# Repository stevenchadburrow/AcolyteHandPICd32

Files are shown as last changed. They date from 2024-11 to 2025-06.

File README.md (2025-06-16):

<b><h1>Acolyte Hand PIC'd 32 Retraux Computer and Video Game Console</h1></b>

<b>Background</b>

Why build a "computer"?  Why build a "video game console"?  

I had been programming video games for about 20 years before all of this.  It started in high school on Borland Turbo C++ in the computer lab, and then in college on a Ubuntu Linux computer with g++ and OpenGL.  Most of my early attempts are not even worth mentioning though I tried different genres such as FPS and RTS.  After graduate school and getting a job at the local college as a math teacher, I began trying to make a non-violent video game, namely a <a href="https://en.wikipedia.org/wiki/Harvest_Moon_(video_game)">Harvest Moon</a> clone.  It seems that <a href="https://en.wikipedia.org/wiki/Stardew_Valley">Stardew Valley</a> beat me to it!  After many attempts on many different platforms, including Linux/OpenGL/C++, HTML/Javascript, and Android/Java, I have declared them all as 'demos', though I learned a lot from that time.  Meanwhile, I began programming 'arcade' video games for our annual Math Appreciation Day events, to have on display and allow students to play during the event.  A few are listed <a href="https://github.com/stevenchadburrow/MathDayGames">here</a>.  

In Fall 2021, after starting research on a water-based calculator, I thought to myself, "Wouldn't electricity be so much easier?"  After stumbling upon <a href="https://wilsonminesco.com/">Garth Wilson's 6502 Primer</a>, I emailed him and he invited me to join the <a href="http://forum.6502.org/">6502.org Forum</a>.  I began researching and prototyping (aka breadboarding) with basic logic chips, and learning how to create schematics.  While learning more about digital electronics, I found The 8-Bit Guy, Adrian's Digital Basement, and Ben Eater on Youtube.

Inspired by The 8-Bit Guy's <a href="https://www.youtube.com/watch?v=ayh0qebfD2g">"Dream Computer"</a>, and after many initial attempts (aka failures) and a couple of awesome successes, I eventually produced the original <a href="https://github.com/stevenchadburrow/AcolyteComputer">Acolyte Computer</a> using a W65C02 processor.  I had great help from Garth Wilson and the guys on the 6502.org Forum as I worked through many prototypes to get to that point.  I was able to display this and other projects at the Math Appreciation Day events playing video games such as Space Invaders, Tetris, and Rogue.

From there, the project grew to the <a href="https://github.com/stevenchadburrow/NewAcolyte">New Acolyte</a> coupled with an XC9572XL CPLD, then the <a href="https://github.com/stevenchadburrow/Acolyte816">Acolyte '816</a> using a W65C816 processor coupled with a PIC16F886 microcontroller as a bootloader.  Wanting to continue pursuing PIC microcontrollers, I created the original <a href="https://github.com/stevenchadburrow/AcolyteHandPICd">Acolyte Hand PIC'd</a> using the PIC18F47J13 microcontroller, then the <a href="https://github.com/stevenchadburrow/AcolyteHandPICd24">Acolyte Hand PIC'd 24</a> using the PIC24EP512GP204 microcontroller finally without a coupled CPLD.  During Summer 2024, I programmed a 2-player <a href="https://www.youtube.com/watch?v=8EHRpKk9gPc">Pokemon demo</a> using <a href="https://tuxemon.org/">Tuxemon</a> art assets, pushing that PIC24 to the limit.

This project, the Acolyte Hand PIC'd 32, is supposed to show the culmination of my knowledge in PCB design and microcontroller programming over the past 3 years.  The intention is to create a standardized development platform for many new video games that will be displayed during the Math Appreciation Day events.

<b>Microcontroller</b>

PIC32MZ2048EFH144 running at 200 MHz
<br>
Internal memory of 512KB of RAM and 2MB of Flash ROM

<b>Video</b>

VGA 800x600 max resolution (720x512 typical resolution) at 72 Hz with 256 colors or 65K colors

<b>Audio</b>

Dual 8-bit audio channels

<b>HID</b>

2x Sega Genesis controller ports
<br>
Dual PS/2 port for keyboard and mouse through splitter
<br>
USB port for keyboard, mouse, or Xbox-360 controller

<b>File System</b>

Elm-Chan's <a href="http://elm-chan.org/fsw/ff/">FatFS Generic FAT Filesystem Module</a> using SPI Micro SD Card adapter
<br>
(use command 'sudo mkfs.vfat /dev/sdX' to format SDcard)

<b>UART</b>

FT232RL USB-to-UART adapter
<br>
(use command 'sudo picocom /dev/ttyUSB0' for default 9600 baud connection)

<b>Custom Applications</b>

Tetra - Tetris clone recopied from my previous PIC-related projects
<br>
Scratchpad - Proof-of-concept 'text editor' without save/load features
<br>
AV Demo - Audio/Video playback of modified video files with a resolution 240x192 at 15 FPS with 65K colors and dual 8-bit audio

<b>Gameboy Emulator</b>

Mahyar Koshkouei's <a href="https://github.com/deltabeard/Peanut-GB">Peanut-GB (with MiniGB-APU) Gameboy Emulator</a>
<br>
Added support for GBC default color palettes, custom palettes, game file save/load, and screen size and refresh rate adjustments
<br>
Tested with many games, including: Tetris, Dr. Mario, Balloon Kid, Zelda: Link's Awakening, Tobu Tobu Girl, Pokemon Red, and Pokemon Kanto Expansion Pak

<b>Links</b>

<a href="https://www.aidanmocke.com/">https://www.aidanmocke.com/</a> for a bunch of PIC32MZ projects (without Harmony), including USB.<br>
<a href="http://elm-chan.org/">http://elm-chan.org/</a> for a bunch of projects, including MMC (aka SDcard) and FatFs.<br>
<a href="https://github.com/deltabeard/">https://github.com/deltabeard/</a> for a bunch of projects, including Peanut-GB and MiniGB-APU projects.<br>
<a href="https://hackaday.com/2025/01/13/homebrew-retro-console-runs-on-pic32/">https://hackaday.com/2025/01/13/homebrew-retro-console-runs-on-pic32/</a> for the Hack-A-Day article!<br>

<b>Look Ma, no bodges! (showing Version 2 board)</b>
<br>
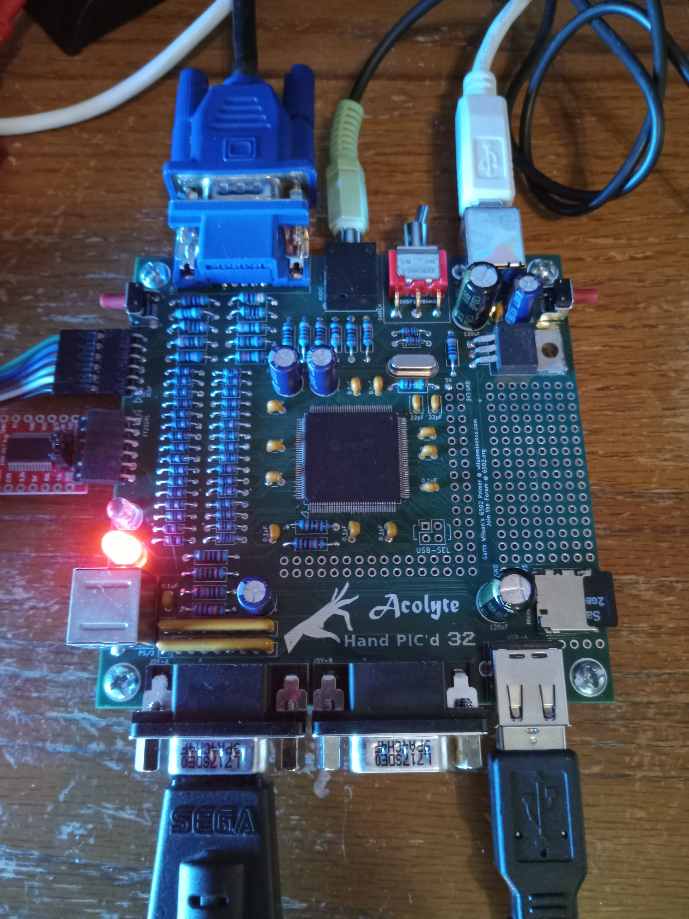
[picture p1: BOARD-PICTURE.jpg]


<b>3D printed case fits perfectly! (showing Version 1 board)</b>
<br>
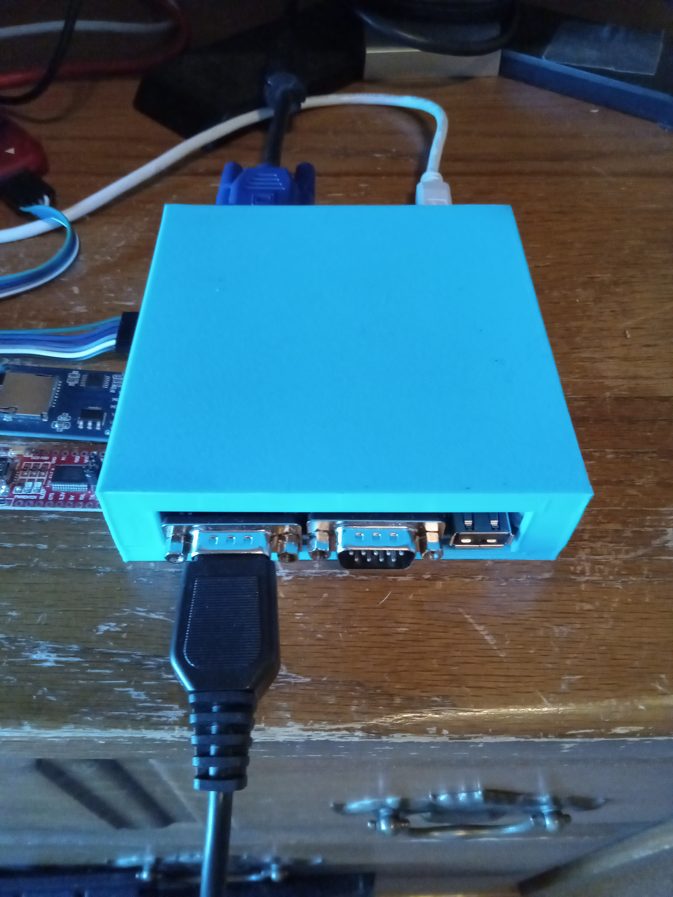
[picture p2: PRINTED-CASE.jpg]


<b>Main menu format with splash screen.</b>
<br>


<b>Gotta love some 2-player Tetris!</b>
<br>
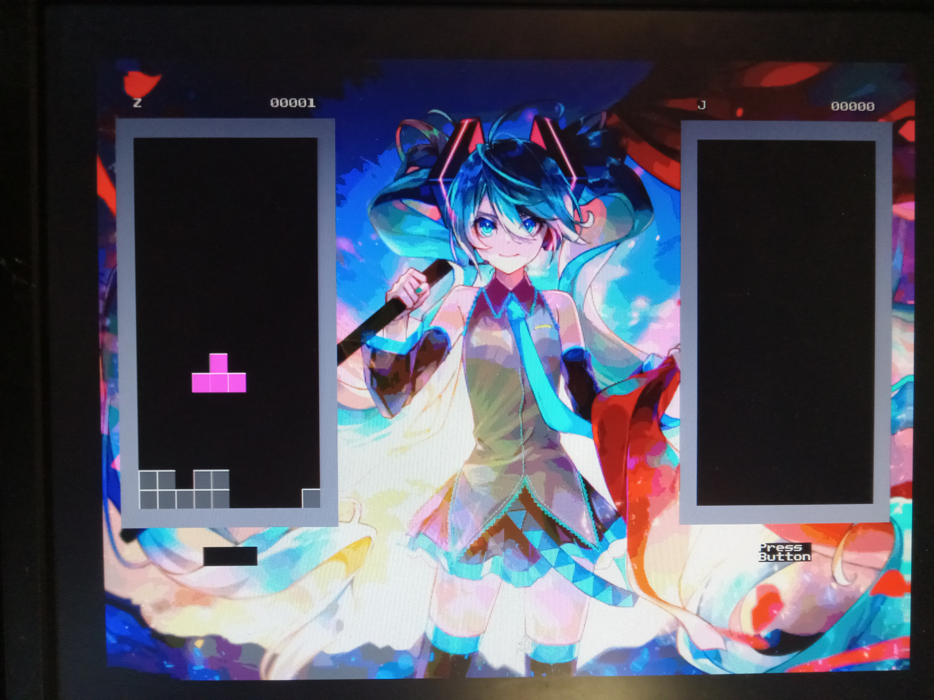
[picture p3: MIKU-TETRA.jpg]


<b>It can now play any Gameboy game!</b>
<br>
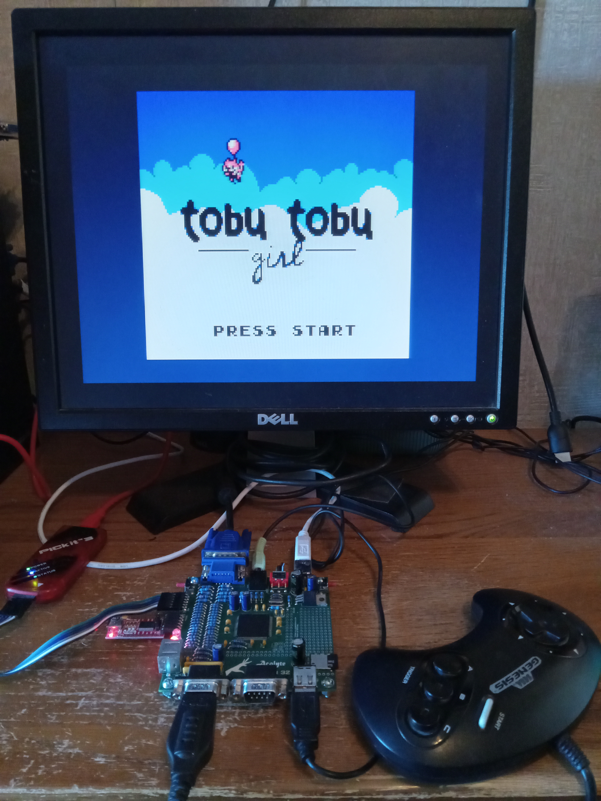
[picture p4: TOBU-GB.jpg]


<b>Audio/Video playback running at 65K colors and dual 8-bit audio.</b>
<br>
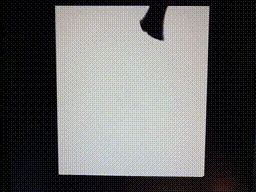
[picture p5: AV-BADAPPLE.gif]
&nbsp;&nbsp;&nbsp;&nbsp;&nbsp;&nbsp;&nbsp;&nbsp;

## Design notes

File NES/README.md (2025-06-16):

<b>NES Emulator for PIC32MZ</b>

*** These files are for the AcolyteHandPICd32 project, but do not show off it's full capability. ***

*** NesEmulator.c is my Linux/OpenGL port, but without audio.  It was made for debugging purposes. ***

These files contain an NES emulator for the PIC32MZ.  It currently is running at 260 MHz (overclocked from 252 MHz max).  Most games run at perfect speed at 20 FPS with audio enabled, even Super Mario Bros 3!

This emulator currently works with the following mappers: NROM, UNROM, CNROM, ANROM, MMC1, and MMC3 (mostly implemented).

Some MMC3 games have issues with IRQ timing, though adjusting both cycle and scanline delays help in most cases.  Mega Man 3, Mega Man 4, and Ninja Gaiden 2 all need these adjusted to even run!  Crystalis needs it adjusted to remove the seam.

Only one hack is currently employed: Sprite priority for Super Mario Bros 3 (though also helps a little in Prince of Persia).

The journey has been documented on the 6502.org Forum, here: http://forum.6502.org/viewtopic.php?f=1&t=8236

Link to a demo video featuring Super Mario Bros 3 here: https://youtu.be/WGrEMQLWrP4

Here is a list of games that are supported, with notes:

1942<br>
1943: Battle for Midway<br>
ADnD: Heroes of the Lance<br>
Adventure Island<br>
Adventure Island 2<br>
Adventure Island 3<br>
Adventures of Lolo<br>
Adventures of Lolo 2<br>
Adventures of Lolo 3<br>
Alwa's Awakening<br>
Arkanoid<br>
Arkista's Ring<br>
Athena<br>
Balloon Fight<br>
Baseball<br>
Battle Kid<br>
Battletoads<Br>
Batman<br>
Battle of Olympus<br>
Bionic Commando<br>
Blade Buster<br>
Blades of Steel<br>
Blaster Master<br>
Boulder Dash<br>
Battletoads and Double Dragon<br>
Bubble Bobble<br>
Castlevania<br>
Castlevania 2<br>
Chip and Dale<br>
Clash at Demonhead<br>
Clu Clu Land<br>
Cobra Triangle<br>
Contra<br>
Championship Rally<br>
Crystalis - Needs IRQ adjustments to remove seam<br>
Double Dragon<br>
Double Dragon 2<br>
Dig Dug<br>
Donkey Kong<br>
Donkey Kong Jr<br>
Double Dribble<br>
Dragon Warrior<br>
Dragon Warrior 2<br>
Dragon Warrior 3<br>
Dragon Warrior 4<br>
Dr. Mario<br>
Duck Tales<br>
Excitebike - Scroll scanline is too high<br>
Faria<br>
Faxanadu<br>
Final Fantasy<br>
Formula One: Built to Win<br>
Galaga<br>
Gauntlet 2 - Needs IRQ adjustments to help seam and status bar, though never perfect<br>
Ghost Lion<br>
Ghosts and Goblins<br>
Golden Guardian Gun Girl<br>
Golf<br>
Gradius<br>
Guardian Legend - Bottom status bar comes in and out sometimes<br>
Ice Climber<br>
Joust<br>
Jurassic Park<br>
Kid Icarus<br>
King's Quest 5<br>
Kira Kira Star Night<br>
Kirby's Adventure<br>
Kung Fu<br>
Layla<br>
Legacy of Wizards<br>
Lemmings<br>
Life Force<br>
Little Mermaid<br>
Little Nemo<br>
Little Samson<br>
LJ-65<br>
Lode Runner<br>
Mach Rider<br>
Marble Madness<br>
Mario Bros<br>
Mega Man<br>
Mega Man 2<br>
Mega Man 3 - Must have IRQ turned off at boot to run<br>
Mega Man 4 - Must have IRQ turned off at boot to run<br>
Mega Man 5<br>
Mega Man 6<br>
Metal Gear<br>
Metroid<br>
Micro Mages<br>
Micro Mages: Second Quest<br>
Miedow<br>
Moon Crystal<br>
Metal Storm<br>
Ninja Gaiden<br>
Ninja Gaiden 2 - Needs IRQ adjusted so game is not halted<br>
Ninja Gaiden 3<br>
Pac-man<br>
Paperboy<br>
Paperboy 2<br>
Prince of Persia - Sprite priority hack only helps a little when behind columns<br>
Project Blue<br>
Rad Racer<br>
Rampage<br>
RC Pro AM<br>
RC Pro AM 2<br>
River City Ransom<br>
S.C.A.T.<br>
Skate or Die<br>
Slalom<br>
Sokoban<br>
Super Mario Bros<br>
Super Mario Bros 2<br>
Super Mario Bros 3 - Sprite priority hack helps a lot, can unadjust IRQ to make multi-scrolling perfect<br>
Super Mario Bros: Lost Levels<br>
Smash TV<br>
Super Off Road<br>
Solstice<br>
Spy Hunter<br>
Silver Surfer<br>
Star Tropics - Top tiles of bottom status bar are cut off<br>
Strider<br>
Super C<br>
Tecmo Super Bowl<br>
Tetris<br>
Time Lord<br>
TMNT<br>
TMNT 2<br>
TMNT 3<br>
Turrican<br>
Ultima: Quest of the Avatar<br>
Wario's Woods<br>
Witch N' Wiz<br>
Wizardry - Proving Grounds<br>
Wizards and Warriors<br>
Pro Wrestling - Needs v-sync flag hack after title screen<br>
Legend of Zelda<br>
Zelda 2: Link's Adventure<br>
Zen: Intergalagic Ninja<br>

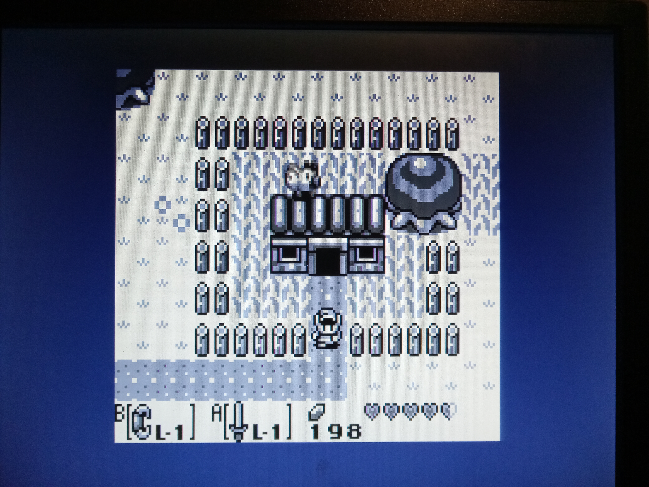
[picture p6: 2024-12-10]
ZELDA-GB.jpg

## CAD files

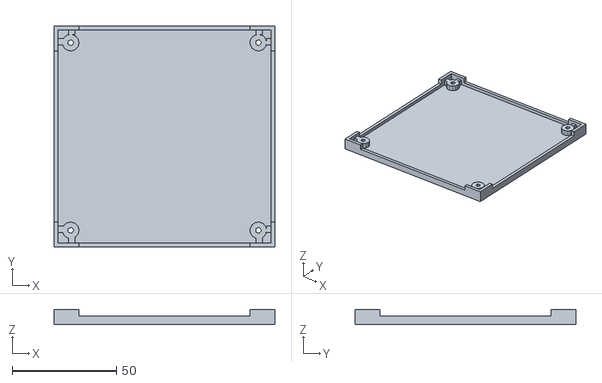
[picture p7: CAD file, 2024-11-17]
HandPICd32-BoxBottom.stl
106.0 x 106.0 x 7.00

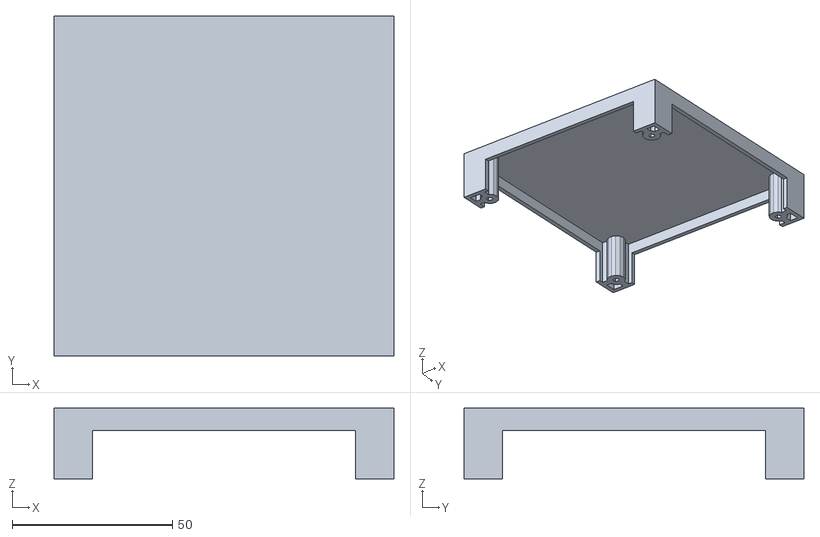
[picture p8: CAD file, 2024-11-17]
HandPICd32-BoxTop.stl
106.0 x 106.0 x 22.0

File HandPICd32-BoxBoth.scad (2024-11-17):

// Both together, just for visuals

//color("#808080") {
shift = 0;



// beginning of top half
rotate([180,0,0]) {
translate([0,-100,-20]) {
    
// top
translate([-3, -3, -2]) {
    difference() {
        cube([106, 106, 2], center = false);
        
    }
}

// back
translate([-3, -3, 0]) {
    difference() {
        cube([106, 2, 20], center = false);
        translate([3+9, -1, 5]) {
            cube([82, 4, 16], center = false);
        }
    }
}

// front
translate([-3, 101, 0]) {
    difference() {
        cube([106, 2, 20], center = false);
        translate([3+9, -1, 5]) {
            cube([82, 4, 16], center = false);
        }
    }
}

// right
translate([-3, -3, 0]) {
    difference() {
        cube([2, 106, 20], center = false);
        translate([-1, 3+9, 5]) {
            cube([4, 82, 16], center = false);
        }
    }
}

// left
translate([101, -3, 0]) {
    difference() {
        cube([2, 106, 20], center = false);
        translate([-1, 3+9, 5]) {
            cube([4, 82, 16], center = false);
        }
    }
}

// corner
translate([5, 5, 0]) {
    difference() {
        cylinder(20, 4, 4);
        translate([0, 0, -1]) {
            cylinder(21.25, 1.5, 1.5);
        }
    }
}
translate([4, -2, 0]) {
    cube([3, 4, 20], center = false);
}
translate([-2, 4, 0]) {
    cube([4, 3, 20], center = false);
}

// corner
translate([95, 5, 0]) {
    difference() {
        cylinder(20, 4, 4);
        translate([0, 0, -1]) {
            cylinder(21.25, 1.5, 1.5);
        }
    }
}
translate([94, -2, 0]) {
    cube([3, 4, 20], center = false);
}
translate([98, 4, 0]) {
    cube([4, 3, 20], center = false);
}

// corner
translate([95, 95, 0]) {
    difference() {
        cylinder(20, 4, 4);
        translate([0, 0, -1]) {
            cylinder(21.25, 1.5, 1.5);
        }
    }
}
translate([94, 98, 0]) {
    cube([3, 4, 20], center = false);
}
translate([98, 94, 0]) {
    cube([4, 3, 20], center = false);
}

// corner
translate([5, 95, 0]) {
    difference() {
        cylinder(20, 4, 4);
        translate([0, 0, -1]) {
            cylinder(21.25, 1.5, 1.5);
        }
    }
}
translate([4, 98, 0]) {
    cube([3, 4, 20], center = false);
}
translate([-2, 94, 0]) {
    cube([4, 3, 20], center = false);
}

}}
// end of top half



// beginning of bottom half
translate([0,0,-5]) {

// bottom
translate([-3, -3, -2]) {
    difference() {
        cube([106, 106, 2], center = false);
        translate([3+5, 3+5, -1]) {
            cylinder(4, 3, 3);
        }
        translate([3+95, 3+5, -1]) {
            cylinder(4, 3, 3);
        }
        translate([3+95, 3+95, -1]) {
            cylinder(4, 3, 3);
        }
        translate([3+5, 3+95, -1]) {
            cylinder(4, 3, 3);
        }
    }
}

// front
translate([-3, -3, 0]) {
    difference() {
        cube([106, 2, 5], center = false);
        translate([12, -5, 2]) {
            cube([82, 10, 4], center = false);
        }
    }
}

// back
translate([-3, 101, 0]) {
    difference() {
        cube([106, 2, 5], center = false);
        translate([12, -5, 2]) {
            cube([82, 10, 4], center = false);
        }
    }
}

// left
translate([-3, -3, 0]) {
    difference() {
        cube([2, 106, 5], center = false);
        translate([-5, 12, 2]) {
            cube([10, 82, 4], center = false);
        }
    }
}

// right
translate([101, -3, 0]) {
    difference() {
        cube([2, 106, 5], center = false);
        translate([-5, 12, 2]) {
            cube([10, 82, 4], center = false);
        }
    }
}

// front left corner
translate([5, 5, 0]) {
    difference() {
        cylinder(3.25, 4, 4);
        translate([0, 0, -1]) {
            cylinder(4.5, 1.5, 1.5);
        }
    }
}
translate([4, -1, 0]) {
    cube([3, 4, 3.25], center = false);
}
translate([-1, 4, 0]) {
    cube([4, 3, 3.25], center = false);
}

// front right corner
translate([95, 5, 0]) {
    difference() {
        cylinder(3.25, 4, 4);
        translate([0, 0, -1]) {
            cylinder(4.5, 1.5, 1.5);
        }
    }
}
translate([94, -1, 0]) {
    cube([3, 4, 3.25], center = false);
}
translate([99, 4, 0]) {
    cube([4, 3, 3.25], center = false);
}

// back right corner
translate([95, 95, 0]) {
    difference() {
        cylinder(3.25, 4, 4);
        translate([0, 0, -1]) {
            cylinder(4.5, 1.5, 1.5);
        }
    }
}
translate([94, 99, 0]) {
    cube([3, 4, 3.25], center = false);
}
translate([99, 94, 0]) {
    cube([4, 3, 3.25], center = false);
}

// back left corner
translate([5, 95, 0]) {
    difference() {
        cylinder(3.25, 4, 4);
        translate([0, 0, -1]) {
            cylinder(4.5, 1.5, 1.5);
        }
    }
}
translate([4, 99, 0]) {
    cube([3, 4, 3.25], center = false);
}
translate([-1, 94, 0]) {
    cube([4, 3, 3.25], center = false);
}
}
// end of bottom half

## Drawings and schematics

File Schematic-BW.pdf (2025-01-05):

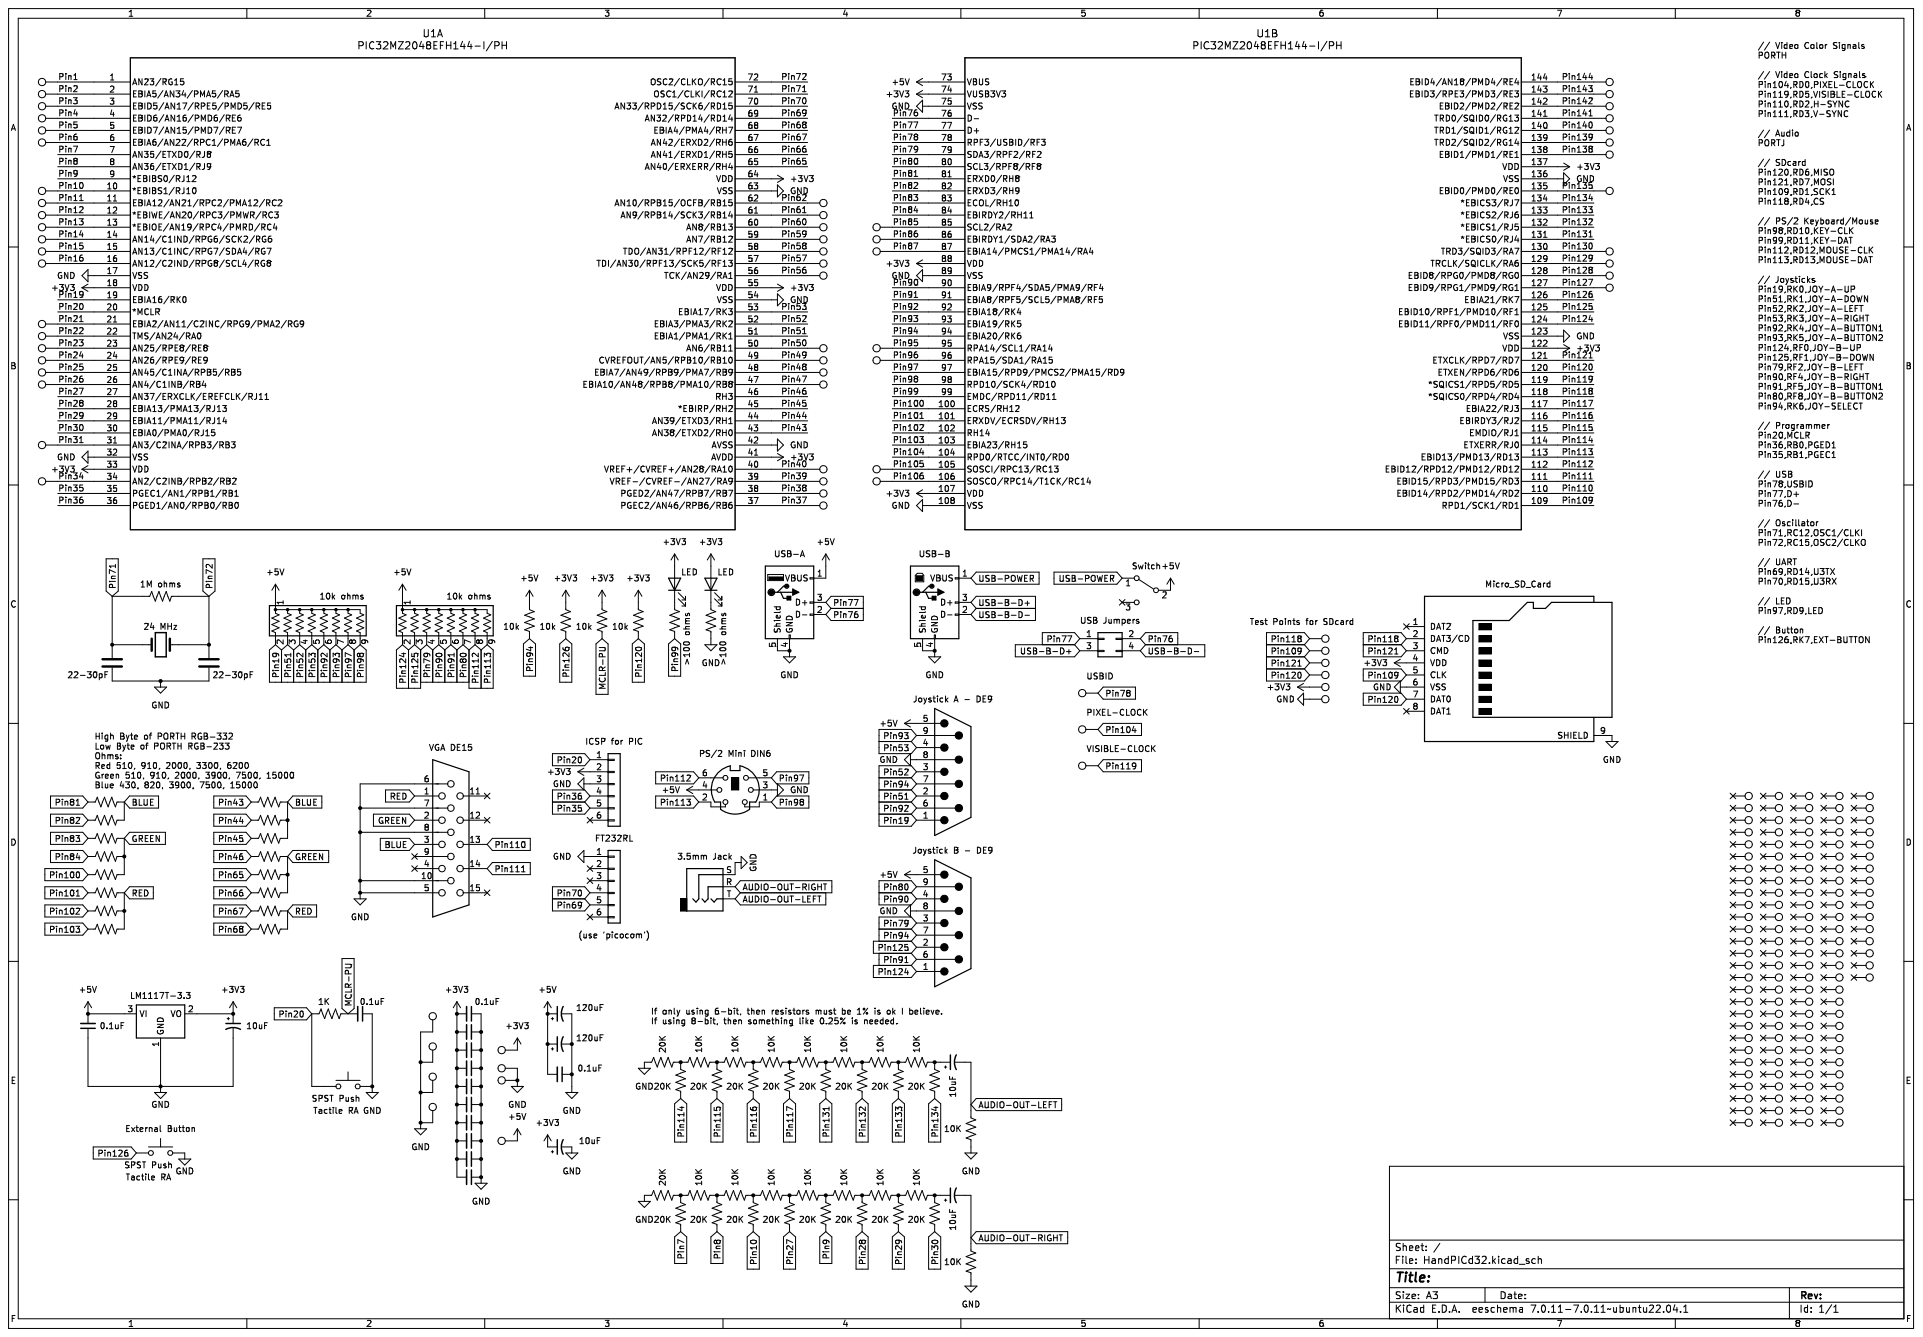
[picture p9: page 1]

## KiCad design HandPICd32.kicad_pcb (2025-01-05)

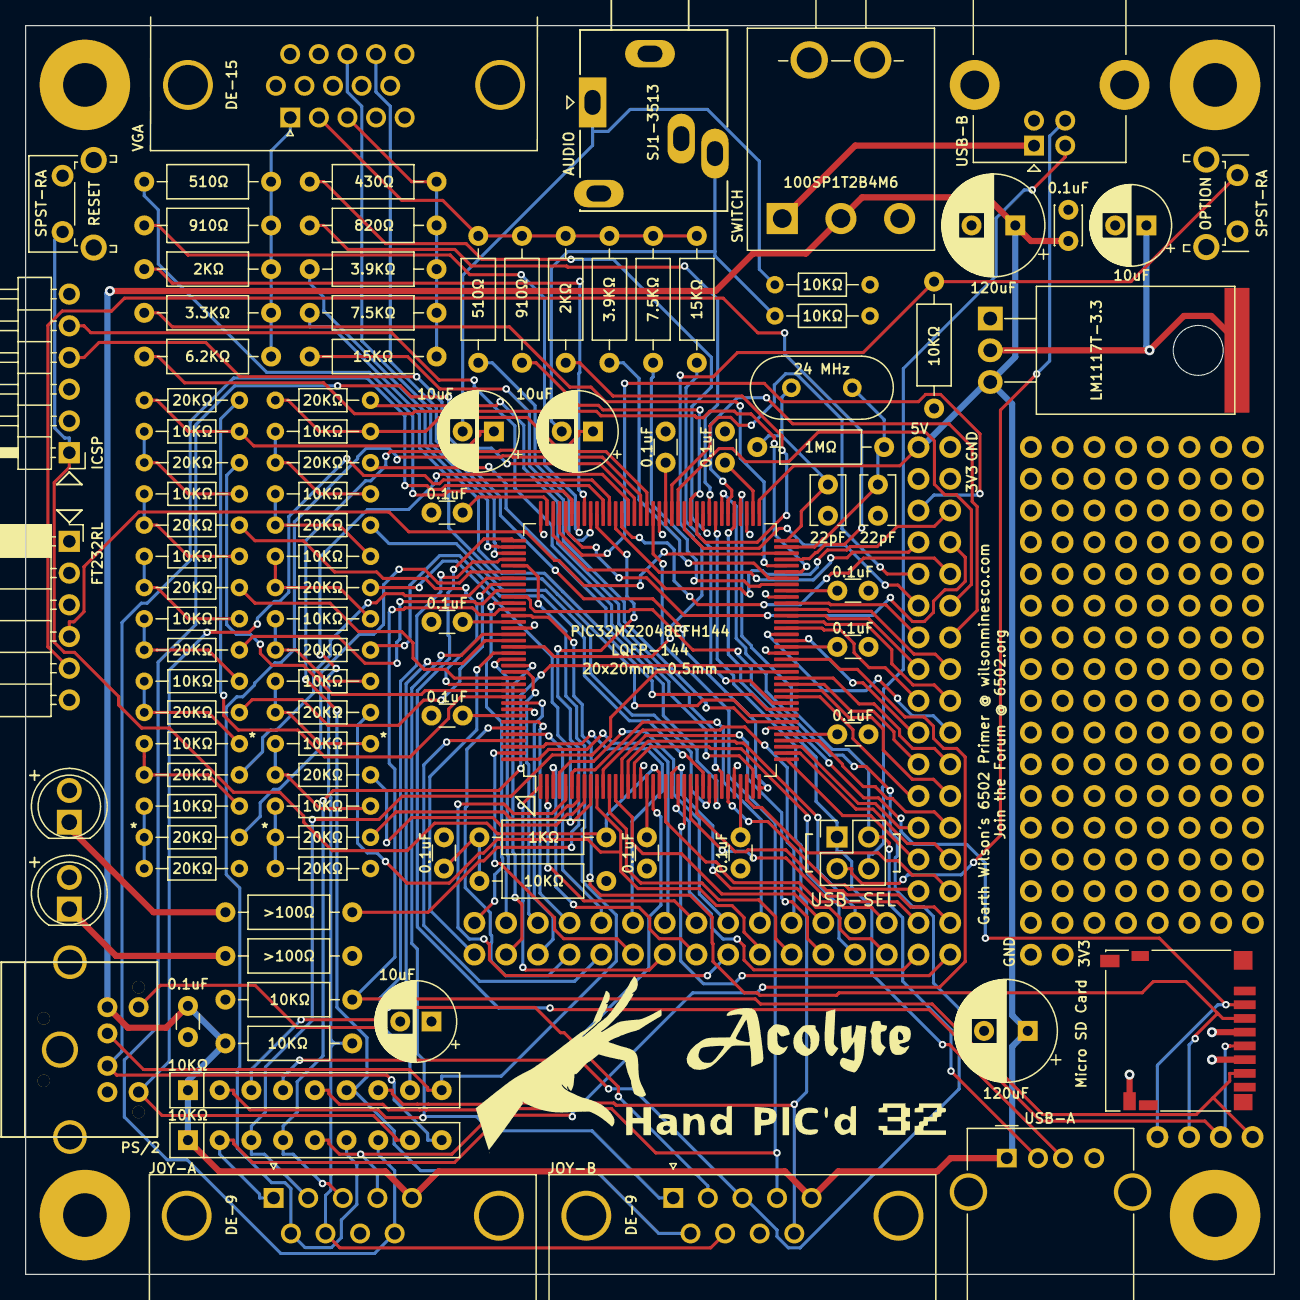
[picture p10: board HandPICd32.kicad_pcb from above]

Board: 4 copper layers, 100.0 x 100.0 mm, 305 parts (1 on the bottom side), 153 nets.

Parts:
C1, C2, C3, C4, C5, C6, C7, C8, C9, C10, C11, C19: C_Small; C_Disc_D3.0mm_W1.6mm_P2.50mm
C12, C13: C; C_Disc_D3.8mm_W2.6mm_P2.50mm
C14, C20: C_Polarized_Small_US; CP_Radial_D8.0mm_P3.50mm
C16, C22, C23, C24: C_Polarized_Small_US; CP_Radial_D6.3mm_P2.50mm
C21: C_Small; C_Disc_D3.0mm_W2.0mm_P2.50mm
D1, D2: LED; CustomLED
G100: LOGO; HandPinching
G101: LOGO; AcolyteTitle
G102: LOGO; HandPickedTitle
G103: LOGO; PublicPixel32
G104: LOGO; Mystery
J1: Mini-DIN-6; PS2_Din6
J2, J7: DE9_Plug; DSUB-9_Male_Horizontal_P2.77x2.84mm_EdgePinOffset7.70mm_Hou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
J4: DE15_Receptacle_HighDensity; DSUB-15-HD_Female_Horizontal_P2.29x2.54mm_VGA
J5: USB_B; USB_B_Lumberg_2411_02_Horizontal
J6: USB_A; USB_A_Molex_67643_Horizontal
J8: AudioJack3; BIGJack_3.5mm_Ledino_KB3SPRS_Horizontal
J9: Conn_01x06; PinHeader_1x06_P2.54mm_Horizontal
J11: Micro_SD_Card; microSD_HC_Hirose_DM3D-SF
J12: Conn_01x06; PinSocket_1x06_P2.54mm_Horizontal
J14: Conn_02x02_Odd_Even; PinHeader_2x02_P2.54mm_Vertical
R1, R2, R3, R4, R5, R6, R7, R8, R9, R10, R11, R16, R17, R18, R19, R22, R51, R52, R53, R54, R55, R56, R57, R58: R_US; R_Axial_DIN0207_L6.3mm_D2.5mm_P10.16mm_Horizontal
R12, R13, R14, R15, R20, R21, R23, R24, R25, R26, R27, R28, R29, R30, R31, R32, R33, R34, R35, R36, R37, R38, R39, R40, R41, R42, R43, R44, R45, R46, R47, R48, R49, R50: R_US; R_Axial_DIN0204_L3.6mm_D1.6mm_P7.62mm_Horizontal
RN1, RN2: R_Network08_US; R_Array_SIP9
SW1: SW_SPDT; SPDT-100SP1T2B4M6QE
SW2, SW3: SW_Push; SW_Tactile_SPST_Angled_PTS645Vx83-2LFS
TP1, TP2, TP3, TP4, TP5, TP6, TP7, TP8, TP9, TP10, TP11, TP12, TP13, TP14, TP15, TP16, TP17, TP18, TP19, TP20, TP21, TP22, TP23, TP24, TP25, TP26, TP28, TP30, TP36, TP37, TP38, TP39, TP40, TP44, TP45, TP46, TP47, TP50, TP51, TP52, TP53, TP54, TP55, TP58, TP65, TP72, TP73, TP74, TP80, TP81, TP89, TP90, TP91, TP103, TP105, TP106, TP107, TP108, TP115, TP117, TP118, TP119, TP120, TP122, TP123, TP124, TP132, TP137, TP150, TP152, TP154, TP155, TP156, TP157, TP158, TP159, TP160, TP161, TP162, TP163, TP164, TP165, TP166, TP167, TP168, TP169, TP170, TP171, TP172, TP173, TP174, TP175, TP176, TP177, TP178, TP179, TP180, TP181, TP182, TP183, TP184, TP185, TP186, TP187, TP188, TP189, TP190, TP191, TP192, TP193, TP194, TP195, TP196, TP197, TP198, TP199, TP200, TP201, TP202, TP203, TP204, TP205, TP206, TP207, TP208, TP209, TP210, TP211, TP212, TP213, TP214, TP215, TP216, TP217, TP218, TP219, TP220, TP221, TP222, TP223, TP224, TP225, TP226, TP227, TP228, TP229, TP230, TP231, TP232, TP233, TP234, TP235, TP236, TP237, TP238, TP239, TP240, TP241, TP242, TP243, TP244, TP245, TP246, TP247, TP248, TP249, TP250, TP251, TP252, TP253, TP254, TP255, TP256, TP257, TP258, TP259, TP260, TP261, TP262, TP263, TP264, TP265, TP266, TP267, TP268, TP269, TP270, TP271, TP272, TP273, TP274, TP275, TP276, TP277, TP278, TP279: TestPoint; TestPointStdTHT
TP133, TP134, TP135, TP136: TestPoint; ScrewHole-4-40
U1: PIC32MZ2048EFH144-I/PH; LQFP-144_20x20mm_P0.5mm-CUSTOM
U4: LM1117T-3.3; TO-220-3_Horizontal_TabDown-custom
Y1: Crystal; Crystal_HC49-4H_Vertical

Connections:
+3V3: C1.2, C2.2, C3.2, C4.2, C5.2, C6.2, C7.2, C8.2, C9.2, C10.2, C22.1, C23.1, D1.2 (A), D2.2 (A), J9.2, J11.4 (VDD), R2.2, R18.2, R22.2, TP25.1, TP58.1, U1.18 (VDD), U1.33 (VDD), U1.41 (AVDD), U1.55 (VDD), U1.64 (VDD), U1.74 (VUSB3V3), U1.88 (VDD), U1.107 (VDD), U1.122 (VDD), U1.137 (VDD), U4.2 (VO)
+5V: C14.1, C19.2, C20.1, C21.2, J1.4, J2.5, J6.1 (VBUS), J7.5, R16.2, RN1.1 (common), RN2.1 (common), SW1.2 (B), TP7.1, U1.73 (VBUS), U4.3 (VI)
/Pin1: TP1.1, U1.1 (AN23/RG15)
/Pin2: TP2.1, U1.2 (EBIA5/AN34/PMA5/RA5)
/Pin3: TP3.1, U1.3 (EBID5/AN17/RPE5/PMD5/RE5)
/Pin4: TP4.1, U1.4 (EBID6/AN16/PMD6/RE6)
/Pin5: TP5.1, U1.5 (EBID7/AN15/PMD7/RE7)
/Pin6: TP6.1, U1.6 (EBIA6/AN22/RPC1/PMA6/RC1)
/Pin11: TP11.1, U1.11 (EBIA12/AN21/RPC2/PMA12/RC2)
/Pin12: TP12.1, U1.12 (*EBIWE/AN20/RPC3/PMWR/RC3)
/Pin13: TP13.1, U1.13 (*EBIOE/AN19/RPC4/PMRD/RC4)
/Pin14: TP14.1, U1.14 (AN14/C1IND/RPG6/SCK2/RG6)
/Pin15: TP15.1, U1.15 (AN13/C1INC/RPG7/SDA4/RG7)
/Pin16: TP16.1, U1.16 (AN12/C2IND/RPG8/SCL4/RG8)
/Pin21: TP17.1, U1.21 (EBIA2/AN11/C2INC/RPG9/PMA2/RG9)
/Pin22: TP18.1, U1.22 (TMS/AN24/RA0)
/Pin23: TP19.1, U1.23 (AN25/RPE8/RE8)
/Pin24: TP20.1, U1.24 (AN26/RPE9/RE9)
/Pin25: TP21.1, U1.25 (AN45/C1INA/RPB5/RB5)
/Pin26: TP22.1, U1.26 (AN4/C1INB/RB4)
/Pin31: TP28.1, U1.31 (AN3/C2INA/RPB3/RB3)
/Pin34: TP30.1, U1.34 (AN2/C2INB/RPB2/RB2)
/Pin37: TP39.1, U1.37 (PGEC2/AN46/RPB6/RB6)
/Pin38: TP38.1, U1.38 (PGED2/AN47/RPB7/RB7)
/Pin39: TP37.1, U1.39 (VREF-/CVREF-/AN27/RA9)
/Pin40: TP36.1, U1.40 (VREF+/CVREF+/AN28/RA10)
/Pin47: TP47.1, U1.47 (EBIA10/AN48/RPB8/PMA10/RB8)
/Pin48: TP46.1, U1.48 (EBIA7/AN49/RPB9/PMA7/RB9)
/Pin49: TP45.1, U1.49 (CVREFOUT/AN5/RPB10/RB10)
/Pin50: TP44.1, U1.50 (AN6/RB11)
/Pin56: TP40.1, U1.56 (TCK/AN29/RA1)
/Pin57: TP55.1, U1.57 (TDI/AN30/RPF13/SCK5/RF13)
/Pin58: TP54.1, U1.58 (TDO/AN31/RPF12/RF12)
/Pin59: TP53.1, U1.59 (AN7/RB12)
/Pin60: TP52.1, U1.60 (AN8/RB13)
/Pin61: TP51.1, U1.61 (AN9/RPB14/SCK3/RB14)
/Pin62: TP50.1, U1.62 (AN10/RPB15/OCFB/RB15)
/Pin85: TP72.1, U1.85 (SCL2/RA2)
/Pin86: TP73.1, U1.86 (EBIRDY1/SDA2/RA3)
/Pin87: TP74.1, U1.87 (EBIA14/PMCS1/PMA14/RA4)
/Pin95: TP80.1, U1.95 (RPA14/SCL1/RA14)
/Pin96: TP81.1, U1.96 (RPA15/SDA1/RA15)
/Pin105: TP90.1, U1.105 (SOSCI/RPC13/RC13)
/Pin106: TP91.1, U1.106 (SOSCO/RPC14/T1CK/RC14)
/Pin127: TP108.1, U1.127 (EBID9/RPG1/PMD9/RG1)
/Pin128: TP107.1, U1.128 (EBID8/RPG0/PMD8/RG0)
/Pin129: TP106.1, U1.129 (TRCLK/SQICLK/RA6)
/Pin130: TP105.1, U1.130 (TRD3/SQID3/RA7)
/Pin135: TP115.1, U1.135 (EBID0/PMD0/RE0)
/Pin138: TP120.1, U1.138 (EBID1/PMD1/RE1)
/Pin139: TP119.1, U1.139 (TRD2/SQID2/RG14)
/Pin140: TP118.1, U1.140 (TRD1/SQID1/RG12)
/Pin141: TP117.1, U1.141 (TRD0/SQID0/RG13)
/Pin142: TP124.1, U1.142 (EBID2/PMD2/RE2)
/Pin143: TP123.1, U1.143 (EBID3/RPE3/PMD3/RE3)
/Pin144: TP122.1, U1.144 (EBID4/AN18/PMD4/RE4)
AUDIO-OUT-LEFT: C24.2, J8.T, R37.1
AUDIO-OUT-RIGHT: C16.2, J8.R, R50.1
BLUE: J4.3, R3.1, R4.1, R51.1, R52.1, R58.1
GND: C1.1, C2.1, C3.1, C4.1, C5.1, C6.1, C7.1, C8.1, C9.1, C10.1, C11.1, C12.2, C13.2, C14.2, C19.1, C20.2, C21.1, C22.2, C23.2, J1.3, J2.8, J4.5, J4.6, J4.7, J4.8, J4.10, J5.4 (GND), J5.5 (Shield), J6.4 (GND), J6.5 (Shield), J7.8, J8.S, J9.3, J11.6 (VSS), J11.9 (SHIELD), J12.1, R12.2, R17.2, R36.2, R37.2, R50.2, SW2.2, SW3.2, TP26.1, TP132.1, TP133.1, TP134.1, TP135.1, TP136.1, TP137.1, U1.17 (VSS), U1.32 (VSS), U1.42 (AVSS), U1.54 (VSS), U1.63 (VSS), U1.75 (VSS), U1.89 (VSS), U1.108 (VSS), U1.123 (VSS), U1.136 (VSS), U4.1 (GND)
GREEN: J4.2, R5.1, R6.1, R7.1, R53.1, R54.1, R55.1
MCLR-PU: C11.2, R1.1, R22.1
unnamed: C16.1, R48.1, R49.2
unnamed: C24.1, R34.1, R35.2
unnamed: D1.1 (K), R17.1
unnamed: D2.1 (K), R19.1
unnamed: R12.1, R13.2, R14.2
unnamed: R14.1, R15.2, R38.2
unnamed: R20.2, R21.2, R36.1
unnamed: R21.1, R23.2, R24.2
unnamed: R24.1, R25.2, R26.2
unnamed: R26.1, R27.2, R28.2
unnamed: R28.1, R29.2, R30.2
unnamed: R30.1, R31.2, R32.2
unnamed: R32.1, R33.2, R34.2
unnamed: R38.1, R39.2, R40.2
unnamed: R40.1, R41.2, R42.2
unnamed: R42.1, R43.2, R44.2
unnamed: R44.1, R45.2, R46.2
unnamed: R46.1, R47.2, R48.2
Pin7: R13.1, U1.7 (AN35/ETXD0/RJ8)
Pin8: R15.1, U1.8 (AN36/ETXD1/RJ9)
Pin9: R43.1, U1.9 (*EBIBS0/RJ12)
Pin10: R39.1, TP10.1, U1.10 (*EBIBS1/RJ10)
Pin19: J2.1, RN2.2 (R1), U1.19 (EBIA16/RK0)
Pin20: J9.1, R1.2, SW2.1, U1.20 (*MCLR)
Pin27: R41.1, U1.27 (AN37/ERXCLK/EREFCLK/RJ11)
Pin28: R45.1, U1.28 (EBIA13/PMA13/RJ13)
Pin29: R47.1, U1.29 (EBIA11/PMA11/RJ14)
Pin30: R49.1, U1.30 (EBIA0/PMA0/RJ15)
Pin35: J9.5, U1.35 (PGEC1/AN1/RPB1/RB1)
Pin36: J9.4, U1.36 (PGED1/AN0/RPB0/RB0)
Pin43: R58.2, U1.43 (AN38/ETXD2/RH0)
Pin44: R51.2, U1.44 (AN39/ETXD3/RH1)
Pin45: R52.2, U1.45 (*EBIRP/RH2)
Pin46: R53.2, U1.46 (RH3)
Pin51: J2.2, RN2.3 (R2), U1.51 (EBIA1/PMA1/RK1)
Pin52: J2.3, RN2.4 (R3), U1.52 (EBIA3/PMA3/RK2)
Pin53: J2.4, RN2.5 (R4), U1.53 (EBIA17/RK3)
Pin65: R54.2, U1.65 (AN40/ERXERR/RH4)
Pin66: R55.2, U1.66 (AN41/ERXD1/RH5)
Pin67: R56.2, U1.67 (AN42/ERXD2/RH6)
Pin68: R57.2, U1.68 (EBIA4/PMA4/RH7)
Pin69: J12.5, U1.69 (AN32/RPD14/RD14)
Pin70: J12.4, U1.70 (AN33/RPD15/SCK6/RD15)
Pin71: C12.1, R11.1, U1.71 (OSC1/CLKI/RC12), Y1.1
Pin72: C13.1, R11.2, U1.72 (OSC2/CLKO/RC15), Y1.2
Pin76: J6.2 (D-), J14.2, U1.76 (D-)
Pin77: J6.3 (D+), J14.1, U1.77 (D+)
Pin78: TP65.1, U1.78 (RPF3/USBID/RF3)
Pin79: J7.3, RN1.4 (R3), U1.79 (SDA3/RPF2/RF2)
Pin80: J7.9, RN1.7 (R6), U1.80 (SCL3/RPF8/RF8)
Pin81: R3.2, U1.81 (ERXD0/RH8)
Pin82: R4.2, U1.82 (ERXD3/RH9)
Pin83: R5.2, U1.83 (ECOL/RH10)
Pin84: R6.2, U1.84 (EBIRDY2/RH11)
Pin90: J7.4, RN1.5 (R4), U1.90 (EBIA9/RPF4/SDA5/PMA9/RF4)
Pin91: J7.6, RN1.6 (R5), U1.91 (EBIA8/RPF5/SCL5/PMA8/RF5)
Pin92: J2.6, RN2.6 (R5), U1.92 (EBIA18/RK4)
Pin93: J2.9, RN2.7 (R6), U1.93 (EBIA19/RK5)
Pin94: J2.7, J7.7, R16.1, U1.94 (EBIA20/RK6)
Pin97: J1.5, RN2.8 (R7), U1.97 (EBIA15/RPD9/PMCS2/PMA15/RD9)
Pin98: J1.1, RN2.9 (R8), U1.98 (RPD10/SCK4/RD10)
Pin99: R19.2, U1.99 (EMDC/RPD11/RD11)
Pin100: R7.2, U1.100 (ECRS/RH12)
Pin101: R8.2, U1.101 (ERXDV/ECRSDV/RH13)
Pin102: R9.2, U1.102 (RH14)
Pin103: R10.2, U1.103 (EBIA23/RH15)
Pin104: TP89.1, U1.104 (RPD0/RTCC/INT0/RD0)
Pin109: J11.5 (CLK), TP9.1, U1.109 (RPD1/SCK1/RD1)
Pin110: J4.13, U1.110 (EBID14/RPD2/PMD14/RD2)
Pin111: J4.14, U1.111 (EBID15/RPD3/PMD15/RD3)
Pin112: J1.6, RN1.8 (R7), U1.112 (EBID12/RPD12/PMD12/RD12)
Pin113: J1.2, RN1.9 (R8), U1.113 (EBID13/PMD13/RD13)
Pin114: R20.1, U1.114 (ETXERR/RJ0)
Pin115: R23.1, U1.115 (EMDIO/RJ1)
Pin116: R25.1, U1.116 (EBIRDY3/RJ2)
Pin117: R27.1, U1.117 (EBIA22/RJ3)
Pin118: J11.2 (DAT3/CD), TP8.1, U1.118 (*SQICS0/RPD4/RD4)
Pin119: TP103.1, U1.119 (*SQICS1/RPD5/RD5)
Pin120: J11.7 (DAT0), R2.1, TP24.1, U1.120 (ETXEN/RPD6/RD6)
Pin121: J11.3 (CMD), TP23.1, U1.121 (ETXCLK/RPD7/RD7)
Pin124: J7.1, RN1.2 (R1), U1.124 (EBID11/RPF0/PMD11/RF0)
Pin125: J7.2, RN1.3 (R2), U1.125 (EBID10/RPF1/PMD10/RF1)
Pin126: R18.1, SW3.1, U1.126 (EBIA21/RK7)
Pin131: R29.1, U1.131 (*EBICS0/RJ4)
Pin132: R31.1, U1.132 (*EBICS1/RJ5)
Pin133: R33.1, U1.133 (*EBICS2/RJ6)
Pin134: R35.1, U1.134 (*EBICS3/RJ7)
RED: J4.1, R8.1, R9.1, R10.1, R56.1, R57.1
USB-B-D+: J5.3 (D+), J14.3
USB-B-D-: J5.2 (D-), J14.4
USB-POWER: J5.1 (VBUS), SW1.1 (A)

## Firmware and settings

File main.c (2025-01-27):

// Hand PIC'd 32
// By: Professor Steven Chad Burrow


// comment out if you want to program the PIC32 faster
#define SPLASH


/*
VESA Signal 800 x 600 @ 72 Hz timing

Interested in easy to use VGA solution for embedded applications? Click here!

General timing
Screen refresh rate	72 Hz
Vertical refresh	48.076923076923 kHz
Pixel freq.	50.0 MHz
Horizontal timing (line)
Polarity of horizontal sync pulse is positive.

Scanline part	Pixels	Time [µs]
Visible area	800	16
Front porch	56	1.12
Sync pulse	120	2.4
Back porch	64	1.28
Whole line	1040	20.8
Vertical timing (frame)
Polarity of vertical sync pulse is positive.

Frame part	Lines	Time [ms]
Visible area	600	12.48
Front porch	37	0.7696
Sync pulse	6	0.1248
Back porch	23	0.4784
Whole frame	666	13.8528
*/

/*	
Interrupt from Visible Timer at beginning of scanline, DMA0 to start.
DMA0 transfers single byte to DMA1 config to enable it.
DMA1 transfers ~400 pixels to PMP on Pixel Timer.
DMA1 chains to DMA2 which transfers a zero to PMP or PORTx.
All of this is independent of sync signals and timers!
Increment line number and change addresses on separate interrupt!
*/ 

/*
// Video Color Signals
PORTH

// Video Clock Signals
Pin104,RD0,PIXEL-CLOCK
Pin119,RD5,VISIBLE-CLOCK
Pin110,RD2,H-SYNC
Pin111,RD3,V-SYNC

// Audio
PORTJ

// SDcard
Pin120,RD6,MISO
Pin121,RD7,MOSI
Pin109,RD1,SCK1
Pin118,RD4,CS

// PS/2 Keyboard/Mouse
Pin98,RD10,KEY-CLK
Pin99,RD11,KEY-DAT
Pin112,RD12,MOUSE-CLK
Pin113,RD13,MOUSE-DAT

// Joysticks
Pin19,RK0,JOY-A-UP
Pin51,RK1,JOY-A-DOWN
Pin52,RK2,JOY-A-LEFT
Pin53,RK3,JOY-A-RIGHT
Pin92,RK4,JOY-A-BUTTON1
Pin93,RK5,JOY-A-BUTTON2
Pin124,RF0,JOY-B-UP
Pin125,RF1,JOY-B-DOWN
Pin79,RF2,JOY-B-LEFT
Pin90,RF4,JOY-B-RIGHT
Pin91,RF5,JOY-B-BUTTON1
Pin80,RF8,JOY-B-BUTTON2
Pin94,RK6,JOY-SELECT

// Programmer
Pin20,MCLR
Pin36,RB0,PGED1
Pin35,RB1,PGEC1

// USB
Pin78,USBID
Pin77,D+
Pin76,D-

// Oscillator
Pin71,RC12,OSC1/CLKI
Pin72,RC15,OSC2/CLKO

// UART
Pin69,RD14,U3TX
Pin70,RD15,U3RX

// LED
Pin97,RD9,LED

// Button
Pin126,RK7,EXT-BUTTON
*/




// PIC32MZ2048EFM144 Configuration Bit Settings

// 'C' source line config statements

// DEVCFG3
#pragma config USERID = 0xFFFF          // Enter Hexadecimal value (Enter Hexadecimal value)
#pragma config FMIIEN = ON              // Ethernet RMII/MII Enable (MII Enabled)
#pragma config FETHIO = OFF             // Ethernet I/O Pin Select (Alternate Ethernet I/O)
#pragma config PGL1WAY = OFF            // Permission Group Lock One Way Configuration (Allow multiple reconfigurations)
#pragma config PMDL1WAY = OFF           // Peripheral Module Disable Configuration (Allow multiple reconfigurations)
#pragma config IOL1WAY = OFF            // Peripheral Pin Select Configuration (Allow multiple reconfigurations)
#pragma config FUSBIDIO = OFF           // USB USBID Selection (Controlled by Port Function)

// DEVCFG2
#pragma config FPLLIDIV = DIV_3         // System PLL Input Divider (3x Divider)
#pragma config FPLLRNG = RANGE_5_10_MHZ// System PLL Input Range (5-10 MHz Input)
#pragma config FPLLICLK = PLL_POSC       // System PLL Input Clock Selection (FRC is input to the System PLL)
#pragma config FPLLMULT = MUL_50       // System PLL Multiplier (PLL Multiply by 50)
#pragma config FPLLODIV = DIV_2         // System PLL Output Clock Divider (2x Divider)
#pragma config UPLLFSEL = FREQ_24MHZ    // USB PLL Input Frequency Selection (USB PLL input is 24 MHz)

// DEVCFG1
#pragma config FNOSC = FRCDIV           // Oscillator Selection Bits (Fast RC Osc w/Div-by-N (FRCDIV))
#pragma config DMTINTV = WIN_127_128    // DMT Count Window Interval (Window/Interval value is 127/128 counter value)
#pragma config FSOSCEN = OFF            // Secondary Oscillator Enable (Disable SOSC)
#pragma config IESO = ON                // Internal/External Switch Over (Enabled)
#pragma config POSCMOD = HS             // Primary Oscillator Configuration (HS osc mode)
#pragma config OSCIOFNC = ON            // CLKO Output Signal Active on the OSCO Pin (Enabled)
#pragma config FCKSM = CSECME           // Clock Switching and Monitor Selection (Clock Switch Enabled, FSCM Enabled)
#pragma config WDTPS = PS1048576        // Watchdog Timer Postscaler (1:1048576)
#pragma config WDTSPGM = STOP           // Watchdog Timer Stop During Flash Programming (WDT stops during Flash programming)
#pragma config WINDIS = NORMAL          // Watchdog Timer Window Mode (Watchdog Timer is in non-Window mode)
#pragma config FWDTEN = OFF             // Watchdog Timer Enable (WDT Disabled)
#pragma config FWDTWINSZ = WINSZ_50     // Watchdog Timer Window Size (Window size is 50%)
#pragma config DMTCNT = DMT31           // Deadman Timer Count Selection (2^31 (2147483648))
#pragma config FDMTEN = OFF             // Deadman Timer Enable (Deadman Timer is disabled)

// DEVCFG0
#pragma config DEBUG = OFF              // Background Debugger Enable (Debugger is disabled)
#pragma config JTAGEN = OFF             // JTAG Enable (JTAG Disabled)
#pragma config ICESEL = ICS_PGx1        // ICE/ICD Comm Channel Select (Communicate on PGEC1/PGED1)
#pragma config TRCEN = OFF               // Trace Disable (Trace features in the CPU are disabled)
#pragma config BOOTISA = MIPS32         // Boot ISA Selection (Boot code and Exception code is MIPS32)
//#pragma config FECCCON = OFF_UNLOCKED   // Dynamic Flash ECC Configuration (ECC and Dynamic ECC are disabled (ECCCON bits are writable))
#pragma config FECCCON = ON             // Dynamic Flash ECC Configuration (Flash ECC is enabled (ECCCON bits are locked))
#pragma config FSLEEP = VREGS           // Flash Sleep Mode (Flash power down is controlled by the VREGS bit)
#pragma config DBGPER = PG_ALL          // Debug Mode CPU Access Permission (Allow CPU access to all permission regions)
#pragma config SMCLR = MCLR_NORM        // Soft Master Clear Enable bit (MCLR pin generates a normal system Reset)
#pragma config SOSCGAIN = GAIN_2X       // Secondary Oscillator Gain Control bits (2x gain setting)
#pragma config SOSCBOOST = OFF          // Secondary Oscillator Boost Kick Start Enable bit (Normal start of the oscillator)
#pragma config POSCGAIN = GAIN_2X       // Primary Oscillator Gain Control bits (2x gain setting)
#pragma config POSCBOOST = OFF          // Primary Oscillator Boost Kick Start Enable bit (Normal start of the oscillator)
#pragma config EJTAGBEN = NORMAL        // EJTAG Boot (Normal EJTAG functionality)

// DEVCP0
#pragma config CP = OFF                 // Code Protect (Protection Disabled)

// SEQ3
#pragma config TSEQ = 0xFFFF            // Boot Flash True Sequence Number (Enter Hexadecimal value)
#pragma config CSEQ = 0xFFFF            // Boot Flash Complement Sequence Number (Enter Hexadecimal value)

// #pragma config statements should precede project file includes.
// Use project enums instead of #define for ON and OFF.

#include <xc.h>

// keeps program code from being written here, reserved for Gameboy
#pragma region name="gb_rom" origin=0x9D100000 size=0x00100000


#define SYS_FREQ 200000000 // Running at 200MHz

unsigned long VirtToPhys(volatile void* p) // changed 'const' to 'volatile'
{
	return (long)p<0?((long)p&0x1fffffffL):(unsigned long)((unsigned long*)p+0x40000000L);
}

void DelayMS(unsigned int s)
{
	unsigned long count = 0x00000000;
	
	count = (unsigned long)((unsigned long)((SYS_FREQ / 1000) * s) / 2); // Convert microseconds us into how many clock ticks it will take
       
	_CP0_SET_COUNT(0); // Set Core Timer count to 0
    
	while (count > _CP0_GET_COUNT()); // Wait until Core Timer count reaches the number we calculated earlier
}

// if using UART, use command 'sudo picocom /dev/ttyUSB0' in Linux
void SendChar(char value)
{
	while (U3STAbits.UTXBF == 1) { }
	U3TXREG = (char)(value);
}

void SendString(char *value)
{
	for (unsigned int i=0; i<256; i++)
	{
		if (value[i] == '\\') break;
		else
		{
			while (U3STAbits.UTXBF == 1) { }
			U3TXREG = (char)(value[i]);
		}
	}
}

void SendHex(unsigned char value)
{
	while (U3STAbits.UTXBF == 1) { }
	if (value/16 >= 10) U3TXREG = (char)(value/16 + 'A' - 10);
	else U3TXREG = (char)(value/16 + '0');
	while (U3STAbits.UTXBF == 1) { }
	if (value%16 >= 10) U3TXREG = (char)(value%16 + 'A' - 10);
	else U3TXREG = (char)(value%16 + '0');
}

void SendLongHex(unsigned long value)
{
	SendHex((unsigned char)(value >> 24));
	SendHex((unsigned char)(value >> 16));
	SendHex((unsigned char)(value >> 8));
	SendHex((unsigned char)(value));
}

#define SCREEN_X 720
#define SCREEN_Y 512

#define HI_SCREEN_X 480
#define HI_SCREEN_Y 384

// video
volatile unsigned char __attribute__((coherent,address(0x8001A000))) screen_buffer[SCREEN_X*SCREEN_Y]; // visible portion of screen

// additional variables
volatile unsigned char __attribute__((coherent)) screen_blank[HI_SCREEN_X*2]; // black scanline
volatile unsigned int screen_scanline = 637; // start of vertical sync
volatile unsigned char screen_zero[2] = { 0x00, 0x00 }; // zero value for black
volatile unsigned char screen_mode = 0; // start in 256-color mode

// audio
volatile unsigned char __attribute__((address(0x80074000))) audio_buffer[2][8192];
volatile unsigned int audio_position = 0;
volatile unsigned int audio_bank = 0;
volatile unsigned int audio_length = 0;
volatile unsigned int audio_switch = 0;
volatile unsigned int frame_position = 0;

// variable arrays
volatile char __attribute__((coherent)) ps2_state_array[2][256];
volatile unsigned int __attribute__((coherent)) ps2_cursor_x[2][256];
volatile unsigned int __attribute__((coherent)) ps2_cursor_y[2][256];
volatile unsigned char __attribute__((coherent)) ps2_mode[2] = { 0x00, 0x00 };
volatile unsigned char __attribute__((coherent)) ps2_writepos[2] = { 0x00, 0x00 };
volatile unsigned char __attribute__((coherent)) ps2_readpos[2] = { 0x00, 0x00 };

volatile char __attribute__((coherent)) usb_state_array[256];
volatile unsigned int __attribute__((coherent)) usb_cursor_x[256];
volatile unsigned int __attribute__((coherent)) usb_cursor_y[256];
volatile unsigned int __attribute__((coherent)) usb_buttons[256];
volatile unsigned char __attribute__((coherent)) usb_mode = 0x00;
volatile unsigned char __attribute__((coherent)) usb_writepos = 0x00;
volatile unsigned char __attribute__((coherent)) usb_readpos = 0x00;

// PS/2 keyboard variables
volatile unsigned char ps2_counter[2] = { 0x00, 0x00 };
volatile unsigned char ps2_buffer[2] = { 0x00, 0x00 };
volatile unsigned char ps2_sequence[2] = { 0xFF, 0xFF }; // starts with 0xFA acknowledge byte
volatile unsigned char ps2_shift[2] = { 0x00, 0x00 };
volatile unsigned char ps2_release[2] = { 0x00, 0x00 };
volatile unsigned char ps2_extended[2] = { 0x00, 0x00 };
volatile unsigned char ps2_ready[2] = { 0x00, 0x00 };
volatile unsigned char ps2_check[2] = { 0x00, 0x00 };
volatile unsigned int ps2_port = 0x0000;
volatile unsigned int ps2_flags = 0x0000;




void ps2_command(unsigned char command, unsigned char port)
{
	CNCONDbits.ON = 0; // turn off interrupt-on-change
	
	unsigned char copy = command;
	
	unsigned char parity_count = 0x00;
	
	for (unsigned char i=0; i<8; i++)
	{
		if ((copy & 0x01) == 0x01) parity_count++;
		
		copy = (copy >> 1);
	}
	
	if (port == 0) // primary port
	{
		PORTDbits.RD9 = 0; // when not floating, ground them
		PORTDbits.RD10 = 0;
		TRISDbits.TRISD9 = 1; // normally they are both floating though
		TRISDbits.TRISD10 = 1; 

		DelayMS(1000); // wait a while for mouse to send it's initial code

		TRISDbits.TRISD9 = 0; // ground clock

		DelayMS(1000); // delay for at least 100 ms

		TRISDbits.TRISD10 = 0; // ground data
		TRISDbits.TRISD9 = 1; // release clock

		while (PORTDbits.RD9 == 0) { } // wait until clock is high

		while (PORTDbits.RD9 == 1) { } // wait until clock is low

		for (unsigned char i=0; i<8; i++)
		{
			if ((command & 0x01) == 0x00)
			{
				TRISDbits.TRISD10 = 0; // ground data
			}
			else
			{
				TRISDbits.TRISD10 = 1; // float data to high
			}

			command = (command >> 1);

			while (PORTDbits.RD9 == 0) { } // wait until clock is high

			while (PORTDbits.RD9 == 1) { } // wait until clock is low
		}

		if (parity_count % 2 == 1) TRISDbits.TRISD10 = 0; // ground data (for parity)
		else TRISDbits.TRISD10 = 1; // float data high (for parity)

		while (PORTDbits.RD9 == 0) { } // wait until clock is high

		while (PORTDbits.RD9 == 1) { } // wait until clock is low

		TRISDbits.TRISD10 = 1; // release data line

		while (PORTDbits.RD10 == 0) { } // wait until data is high

		while (PORTDbits.RD10 == 1) { } // wait until data is low

		while (PORTDbits.RD9 == 1) { } // wait until clock is low

		while (PORTDbits.RD10 == 0) { } // wait until data is high

		while (PORTDbits.RD9 == 0) { } // wait until clock is high
	}
	else if (port == 1) // secondary port (from splitter)
	{
		PORTDbits.RD12 = 0; // when not floating, ground them
		PORTDbits.RD13 = 0;
		TRISDbits.TRISD12 = 1; // normally they are both floating though
		TRISDbits.TRISD13 = 1; 

		DelayMS(1000); // wait a while for mouse to send it's initial code

		TRISDbits.TRISD12 = 0; // ground clock

		DelayMS(1000); // delay for at least 100 ms

		TRISDbits.TRISD13 = 0; // ground data
		TRISDbits.TRISD12 = 1; // release clock

		while (PORTDbits.RD12 == 0) { } // wait until clock is high

		while (PORTDbits.RD12 == 1) { } // wait until clock is low

		for (unsigned char i=0; i<8; i++)
		{
			if ((command & 0x01) == 0x00)
			{
				TRISDbits.TRISD13 = 0; // ground data
			}
			else
			{
				TRISDbits.TRISD13 = 1; // float data to high
			}

			command = (command >> 1);

			while (PORTDbits.RD12 == 0) { } // wait until clock is high

			while (PORTDbits.RD12 == 1) { } // wait until clock is low
		}
		
		if (parity_count % 2 == 1) TRISDbits.TRISD13 = 0; // ground data (for parity)
		else TRISDbits.TRISD13 = 1; // float data high (for parity)

		while (PORTDbits.RD12 == 0) { } // wait until clock is high

		while (PORTDbits.RD12 == 1) { } // wait until clock is low

		TRISDbits.TRISD13 = 1; // release data line

		while (PORTDbits.RD13 == 0) { } // wait until data is high

		while (PORTDbits.RD13 == 1) { } // wait until data is low

		while (PORTDbits.RD12 == 1) { } // wait until clock is low

		while (PORTDbits.RD13 == 0) { } // wait until data is high

		while (PORTDbits.RD12 == 0) { } // wait until clock is high
	}
	
	CNCONDbits.ON = 1; // turn on interrupt-on-change
	
	return;
}



#ifdef SPLASH
#include "splash_default.c"
#endif

#include "tables.c"
#include "usbhost.c"
#include "interrupts.c"
#include "sdcard.c" 

#include "ffconf.h"
#include "ff.h"
#include "ff.c"
#include "diskio.h"
#include "diskio.c"



// frequency in Hz, plays for a short duration
void music_note(unsigned int frequency, unsigned int duration, unsigned char channel)
{
	// each increment of 'audio_buffer[]' is about 20.8 us long
	// each 'audio_switch' is about 170.4 ms long
	
	unsigned int period = (unsigned int)((unsigned long)(1000000 * 5) / (unsigned long)(208 * frequency)) + 1;
	
	unsigned int position = 0;
	
	for (unsigned int i=0; i<8192; i+=period*2)
	{
		for (unsigned int j=0; j<period; j++)
		{
			audio_buffer[0][i+j] = 0x10; // 0x00
			audio_buffer[1][i+j] = 0x10;
		}
		
		for (unsigned int j=0; j<period; j++)
		{
			audio_buffer[0][i+j+period] = 0xF0; // 0x80
			audio_buffer[1][i+j+period] = 0xF0;
		}
		
		position += 2 * period;
	}
	
	audio_length = position;
	
	audio_switch = (unsigned int)((unsigned long)(duration * 8192 * 5) / (unsigned long)(1704 * position)) + 1;
	
	return;
};

char input_ps2_keyboard()
{
	char value = 0x00;
	
	for (unsigned char p=0; p<2; p++)
	{
		if (ps2_ready[p] == 0x01 && ps2_mode[p] == 0x00) // ready and keyboard
		{
			if (ps2_readpos[p] != ps2_writepos[p])
			{
				if (ps2_state_array[p][ps2_readpos[p]] == 0x0B) // release
				{
					ps2_readpos[p]++;
					
					while (ps2_readpos[p] == ps2_writepos[p]) { }
					
					ps2_readpos[p]++; // skip
				}
				else
				{
					value = ps2_state_array[p][ps2_readpos[p]]; // press

					ps2_readpos[p]++;
				}
				
				break;
			}
		}
	}
	
	return value;
};

char input_ps2_mouse(unsigned int *array)
{
	char value = 0x00;
	
	array[0] = 0;
	array[1] = 0;
	array[2] = 0;
	array[3] = 0;
	array[4] = 0;
	
	for (unsigned char p=0; p<2; p++)
	{
		if (ps2_ready[p] == 0x01 && ps2_mode[p] == 0x01) // ready and mouse
		{
			if (ps2_readpos[p] != ps2_writepos[p])
			{
				value = 0x01;
				
				if ((ps2_state_array[p][ps2_readpos[p]] & 0x01) == 0x01) array[0] = 0x0001;
				
				if ((ps2_state_array[p][ps2_readpos[p]] & 0x02) == 0x02) array[1] = 0x0001;
				
				if ((ps2_state_array[p][ps2_readpos[p]] & 0x04) == 0x04) array[2] = 0x0001;
				
				array[3] = (unsigned int)(ps2_cursor_x[p][ps2_readpos[p]]);
				array[4] = (unsigned int)(SCREEN_Y - ps2_cursor_y[p][ps2_readpos[p]]);

				ps2_readpos[p]++;
				
				break;
			}
		}
	}
	
	return value;
};

char input_usb_keyboard()
{
	char value = 0x00;
	
	if (usb_mode == 0x00) // keyboard
	{
		if (usb_readpos != usb_writepos)
		{
			if (usb_state_array[usb_readpos] == 0x0B) // release
			{
				usb_readpos++;
					
				while (usb_readpos == usb_writepos) { }
					
				usb_readpos++; // skip
			}
			else
			{
				value = usb_state_array[usb_readpos]; // press

				usb_readpos++;
			}
		}
	}
	
	return value;
};

char input_usb_mouse(unsigned int *array)
{
	char value = 0x00;
	
	array[0] = 0;
	array[1] = 0;
	array[2] = 0;
	array[3] = 0;
	array[4] = 0;
	
	if (usb_mode == 0x01) // mouse
	{	
		if (usb_readpos != usb_writepos)
		{
			value = 0x01;

			if ((usb_state_array[usb_readpos]) == 0x01) array[0] = 0x0001;

			if ((usb_state_array[usb_readpos]) == 0x02) array[1] = 0x0001;
			
			if ((usb_state_array[usb_readpos]) == 0x03)
			{
				array[0] = 0x0001;
				array[1] = 0x0001;
			}

			if ((usb_state_array[usb_readpos]) == 0x04) array[2] = 0x0001;

			array[3] = (unsigned int)(usb_cursor_x[usb_readpos]);
			array[4] = (unsigned int)(usb_cursor_y[usb_readpos]); //(unsigned int)(384 - usb_cursor_y[usb_readpos]);

			usb_readpos++;
		}
	}
	
	return value;
};
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
int main()
{
	Setup();
	
	DelayMS(1000); // wait some time
	
	SendChar('$'); // just a 'hello world' over the UART
	
	USBHostSetup();
	
	DelayMS(1000); // settling delay, avoid garbage characters
	
	menu_x = 24;
	menu_y = 432;
	menu_pos = 0;
	menu_max = 6; // number of menu items, change accordingly
	
	display_string(menu_x, 16, "Acolyte Hand PIC'd 32\\");

	display_string(menu_x, menu_y,		" Tetra     \\");
	display_string(menu_x, menu_y+8,	" Scratchpad\\");
	display_string(menu_x, menu_y+16,	" AV Demo   \\");
	display_string(menu_x, menu_y+24,	" GB Emu    \\");
	display_string(menu_x, menu_y+32,	" GB Burn   \\");
	display_string(menu_x, menu_y+40,	" Blink Test\\");
	
	char dummy = (char)Menu();
	
	if (dummy == 0) Tetra();
	else if (dummy == 1) Scratchpad();
	else if (dummy == 2) AudioVideoDemo();
	else if (dummy == 3) PeanutGB();
	else if (dummy == 4) BurnROM();
	else if (dummy == 5) { }	
	
	
	SendString("BlinkTest\r\n\\");
	
	while (1)
	{
		// blink LED
		PORTDbits.RD11 = 0;
		DelayMS(100);
		DelayMS(100);
		DelayMS(100);
		DelayMS(100);
		DelayMS(100);

		PORTDbits.RD11 = 1;
		DelayMS(100);
		DelayMS(100);
		DelayMS(100);
		DelayMS(100);
		DelayMS(100);
	}
}

// Unused code below


	
/*
	// NES controller hack
	PORTJbits.RJ4 = 0;
	PORTJbits.RJ5 = 0;
	TRISJbits.TRISJ4 = 0;
	TRISJbits.TRISJ5 = 0;
	TRISJbits.TRISJ15 = 1;
	
	while (1)
	{
		PORTJbits.RJ4 = 1;
		DelayMS(10);
		PORTJbits.RJ4 = 0;
		DelayMS(10);
		
		for (unsigned char i=0; i<8; i++)
		{
			if (PORTJbits.RJ15 == 0) display_character(i*8, 0, '0');
			else display_character(i*8, 0, '1');
			
			PORTJbits.RJ5 = 1;
			DelayMS(10);
			PORTJbits.RJ5 = 0;
			DelayMS(10);
		}
	}
*/

/*
   char dummy = 0x00;

	// infinite loop
	while (1)
	{
		dummy = input_ps2_keyboard();
		
		if (dummy != 0x00)
		{
			while (U3STAbits.UTXBF == 1) { }
			U3TXREG = dummy;
		}
	}
*/
/*	
	unsigned int tune[16*2] = {
		0x063A,	500,
		0x0768,	500,
		0x06FD,	250,
		0x058C,	250,
		0x058C,	500,
		0x058C,	1000,
		0x058C,	1000,
		0x063A,	250,
		0x0850,	250,
		0x06FD,	250,
		0x058C,	250,
		0x058C,	500,
		0x058C,	250,
		0x05FD,	250,
		0x058C,	250,
		0x04F1,	250,
	};
	
	unsigned int pos = 0;
	unsigned int dummy = 0;
	
	while (1)
	{
		music_note(tune[pos], tune[pos+1] - 50, 0);
		
		while (audio_counter[0] > 0) { }
		
		music_note(0xFFFF, 50, 0);
		
		while (audio_counter[0] > 0) { }
		
		pos += 2;
		
		if (pos >= 32)
		{
			for (unsigned int i=0; i<10000; i++)
			{
				for (unsigned int j=0; j<10000; j++)
				{
					dummy++;
				}
			}
			
			pos = 0;
		}
	}
*/	
/*		
		// check if character is ready
		if(U3STAbits.URXDA == 1)
		{
			char dummy = U3RXREG; // get character
			
			U3TXREG = dummy; // echo character
			
			// blink LED
			//PORTDbits.RD11 = 0;
			//DelayMS(250);
			//PORTDbits.RD11 = 1;
		}
*/
/*
		// blink LED
		PORTDbits.RD11 = 0;
		DelayMS(100);

		PORTDbits.RD11 = 1;
		DelayMS(100);
*/
/*
    // Wait for the disk to initialise
    while(disk_initialize(0));
    // Mount the disk
    f_mount(&fso, "", 0);
    // Change dir to the root directory
    f_chdir("/");
    // Open the directory
    f_opendir(&dir, ".");
 
	char buffer[16];
	unsigned int bytes;
	unsigned int result;
	
	for (unsigned int i=0; i<16; i++)
	{
		buffer[i] = 0;
	};
	
	// read in some text
	result = f_open(&file, "/INPUT.TXT", FA_READ);
	if (result == 0)
	{
		while (f_read(&file, buffer, 16, &bytes) == 1) { }
		while (f_close(&file) == 1) { }
	}
	
	// write the same text back
	result = f_open(&file, "/OUTPUT.TXT", FA_WRITE);
	if (result != 0)
	{
		result = f_open(&file, "/OUTPUT.TXT", FA_CREATE_NEW);
		if (result == 0)
		{
			while (f_close(&file) == 1) { }
			result = f_open(&file, "/OUTPUT.TXT", FA_WRITE);
		}
	}
	if (result == 0)
	{
		while (f_write(&file, buffer, 16, &bytes) == 1) { }
		while (f_close(&file) == 1) { }
	}
*/
		/*
		for (unsigned int i=0; i<0x8000; i++)
		{
			if (i % 16 == 0)
			{
				SendLongHex(i);
				SendChar(':');
			}
			
			SendHex(cart_ram[i]);
			SendChar(' ');
			
			if (i % 16 == 15)
			{
				SendChar('\r');
				SendChar('\n');
			}
		}
		*/

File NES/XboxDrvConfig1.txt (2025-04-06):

# might need to 'sudo rmmod xpad' beforehand!  Then do: 'sudo xboxdrv -s -c XboxDrvConfig1.txt'.
# if you need to use the mouse, use REL_X:500:-1 and REL_Y:500:-1 on an axismap, with BTN_LEFT and BTN_RIGHT

[xboxdrv]
ui-clear=true

[ui-axismap]
# x2^dead:1000 = KEY_A:KEY_D 
# y2^dead:1000 = KEY_W:KEY_S 
# x2^dead:1000 = REL_X:500:-1 
# y2^dead:1000 = REL_Y:500:-1

[ui-buttonmap]
# lt = KEY_F
# rt = KEY_F
# lt = BTN_LEFT
# rt = BTN_RIGHT

[ui-axismap]
# x1^dead:1000 = KEY_A:KEY_D
# y1^dead:1000 = KEY_W:KEY_S
# x1^dead:1500 = REL_HWHEEL:5:10
# y1^dead:1500 = REL_WHEEL:5:10

[ui-buttonmap]
a = KEY_Z
b = KEY_X
x = KEY_X
y = KEY_Z
du = KEY_UP
dd = KEY_DOWN
dl = KEY_LEFT
dr = KEY_RIGHT
# a = BTN_MIDDLE

start = KEY_ENTER
back = KEY_SPACE
# start = KEY_ESC
